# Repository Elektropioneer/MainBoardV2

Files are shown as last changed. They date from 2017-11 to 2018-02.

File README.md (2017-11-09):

# Electropioneer Main Board 
This repo is dedicated to developing the new Main Board for the Electropioneer team
## Software
We are using KiCAD to develop the PCB
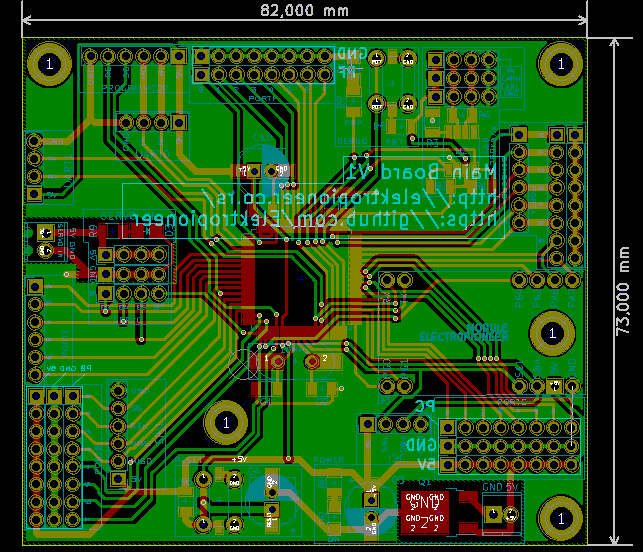
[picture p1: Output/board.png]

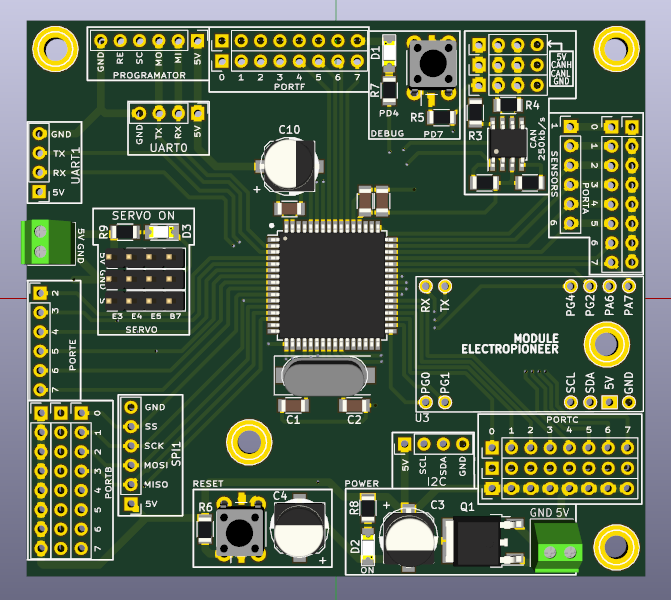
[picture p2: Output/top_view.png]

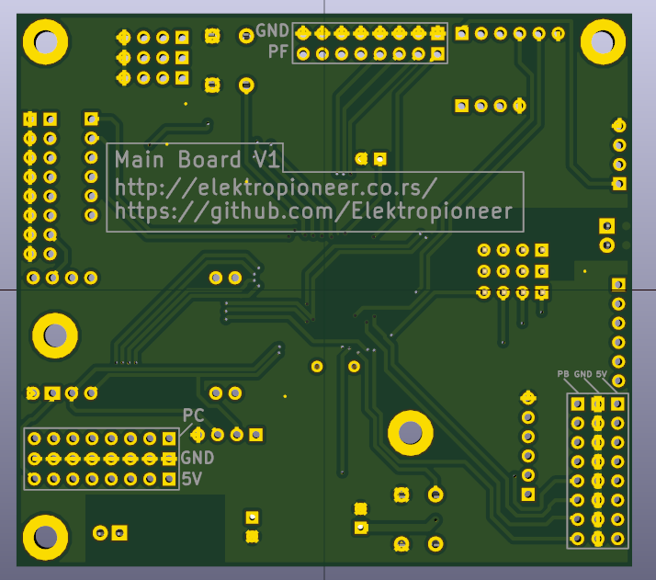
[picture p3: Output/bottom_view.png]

SCHEMATIC PDF

## Protection from reverse current
We are using the simplest way to protect out circuits, a P-Channel MOSFET.
The MOSFET won't turn on when the voltage on the gate is above 0 (exact voltage defined in the datasheet)

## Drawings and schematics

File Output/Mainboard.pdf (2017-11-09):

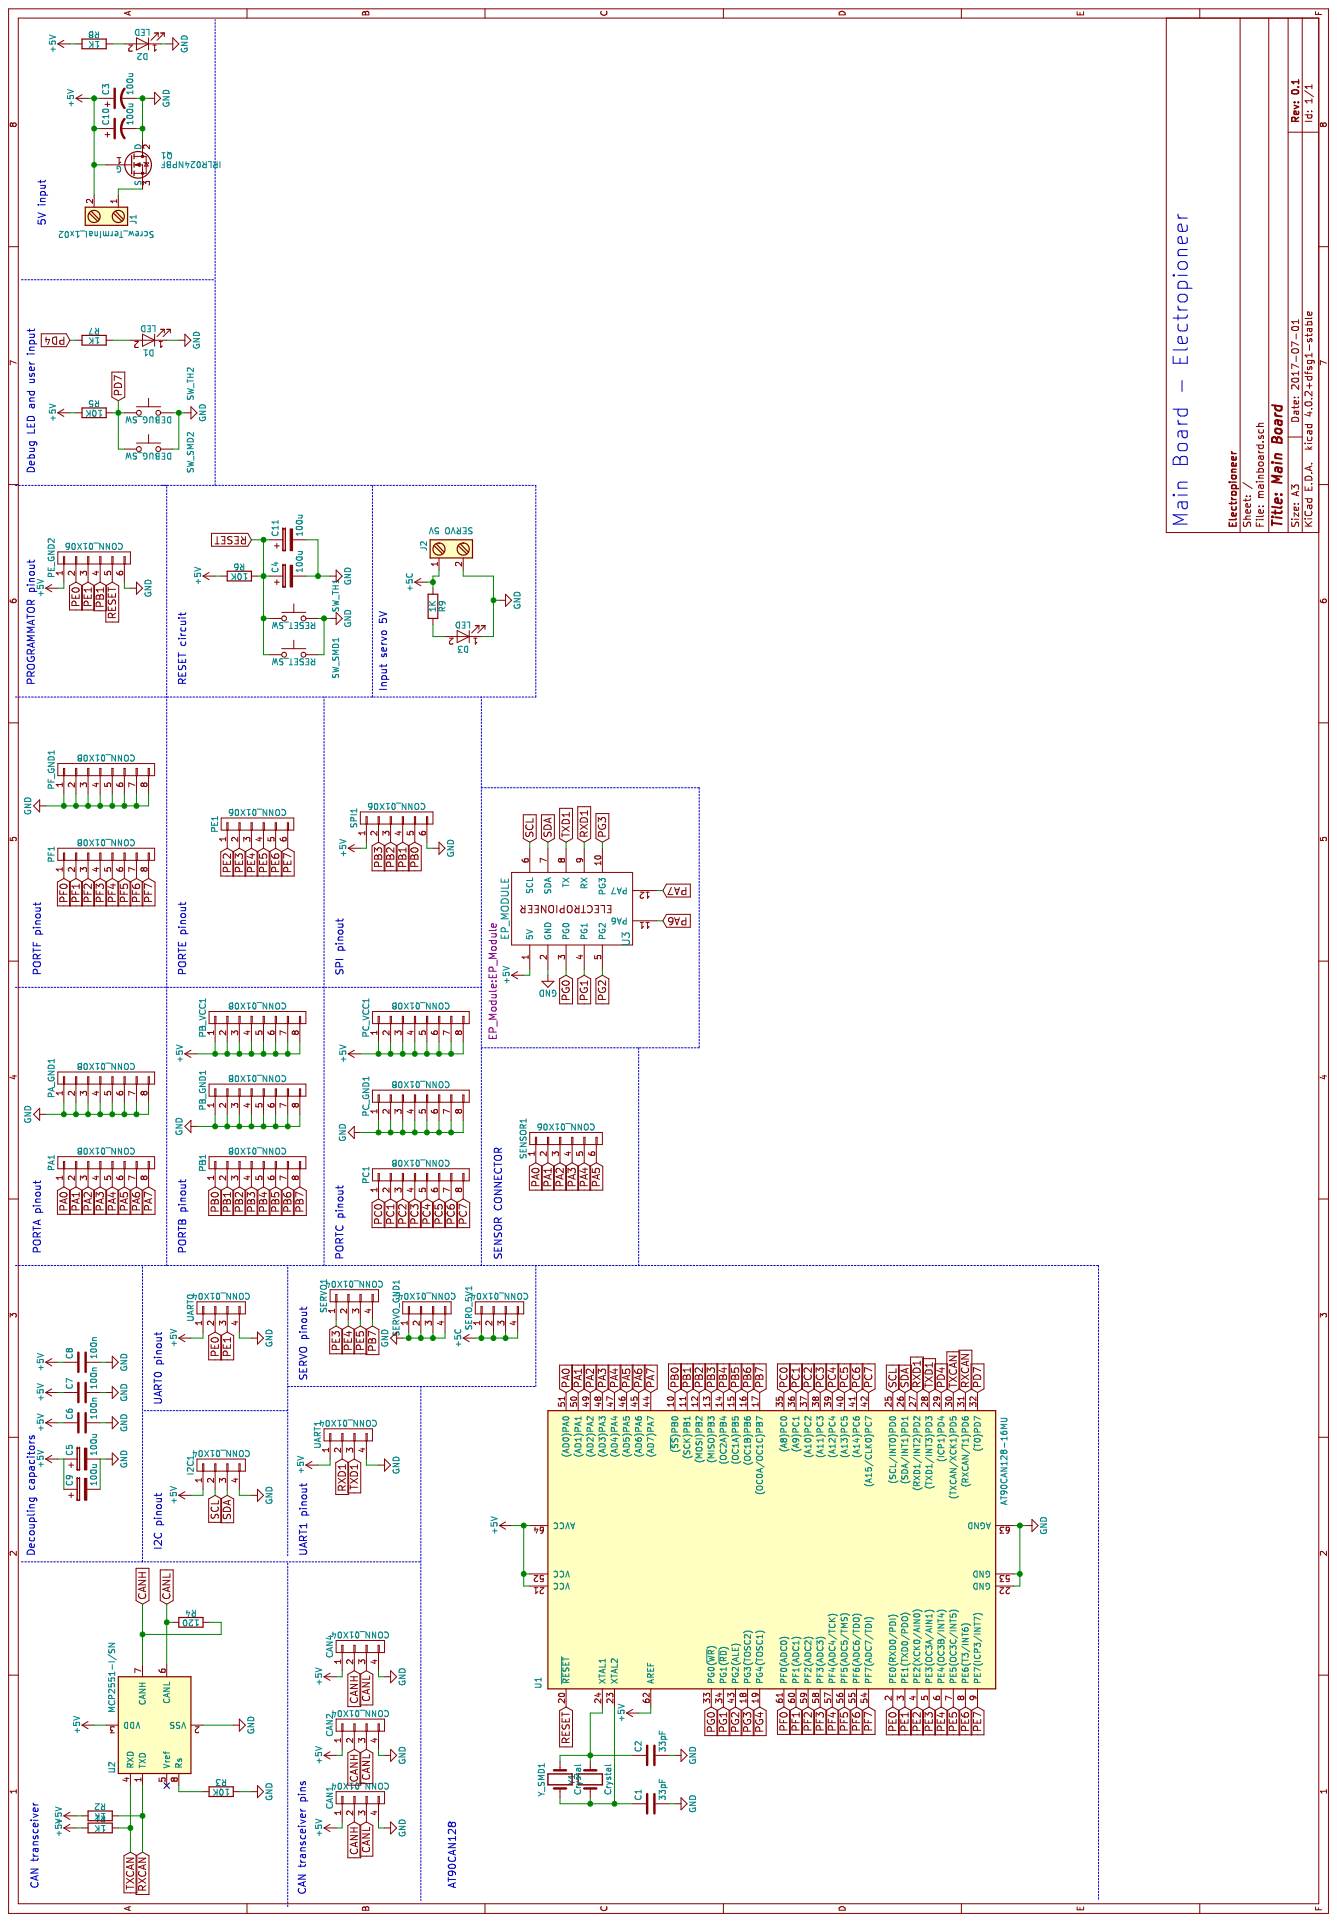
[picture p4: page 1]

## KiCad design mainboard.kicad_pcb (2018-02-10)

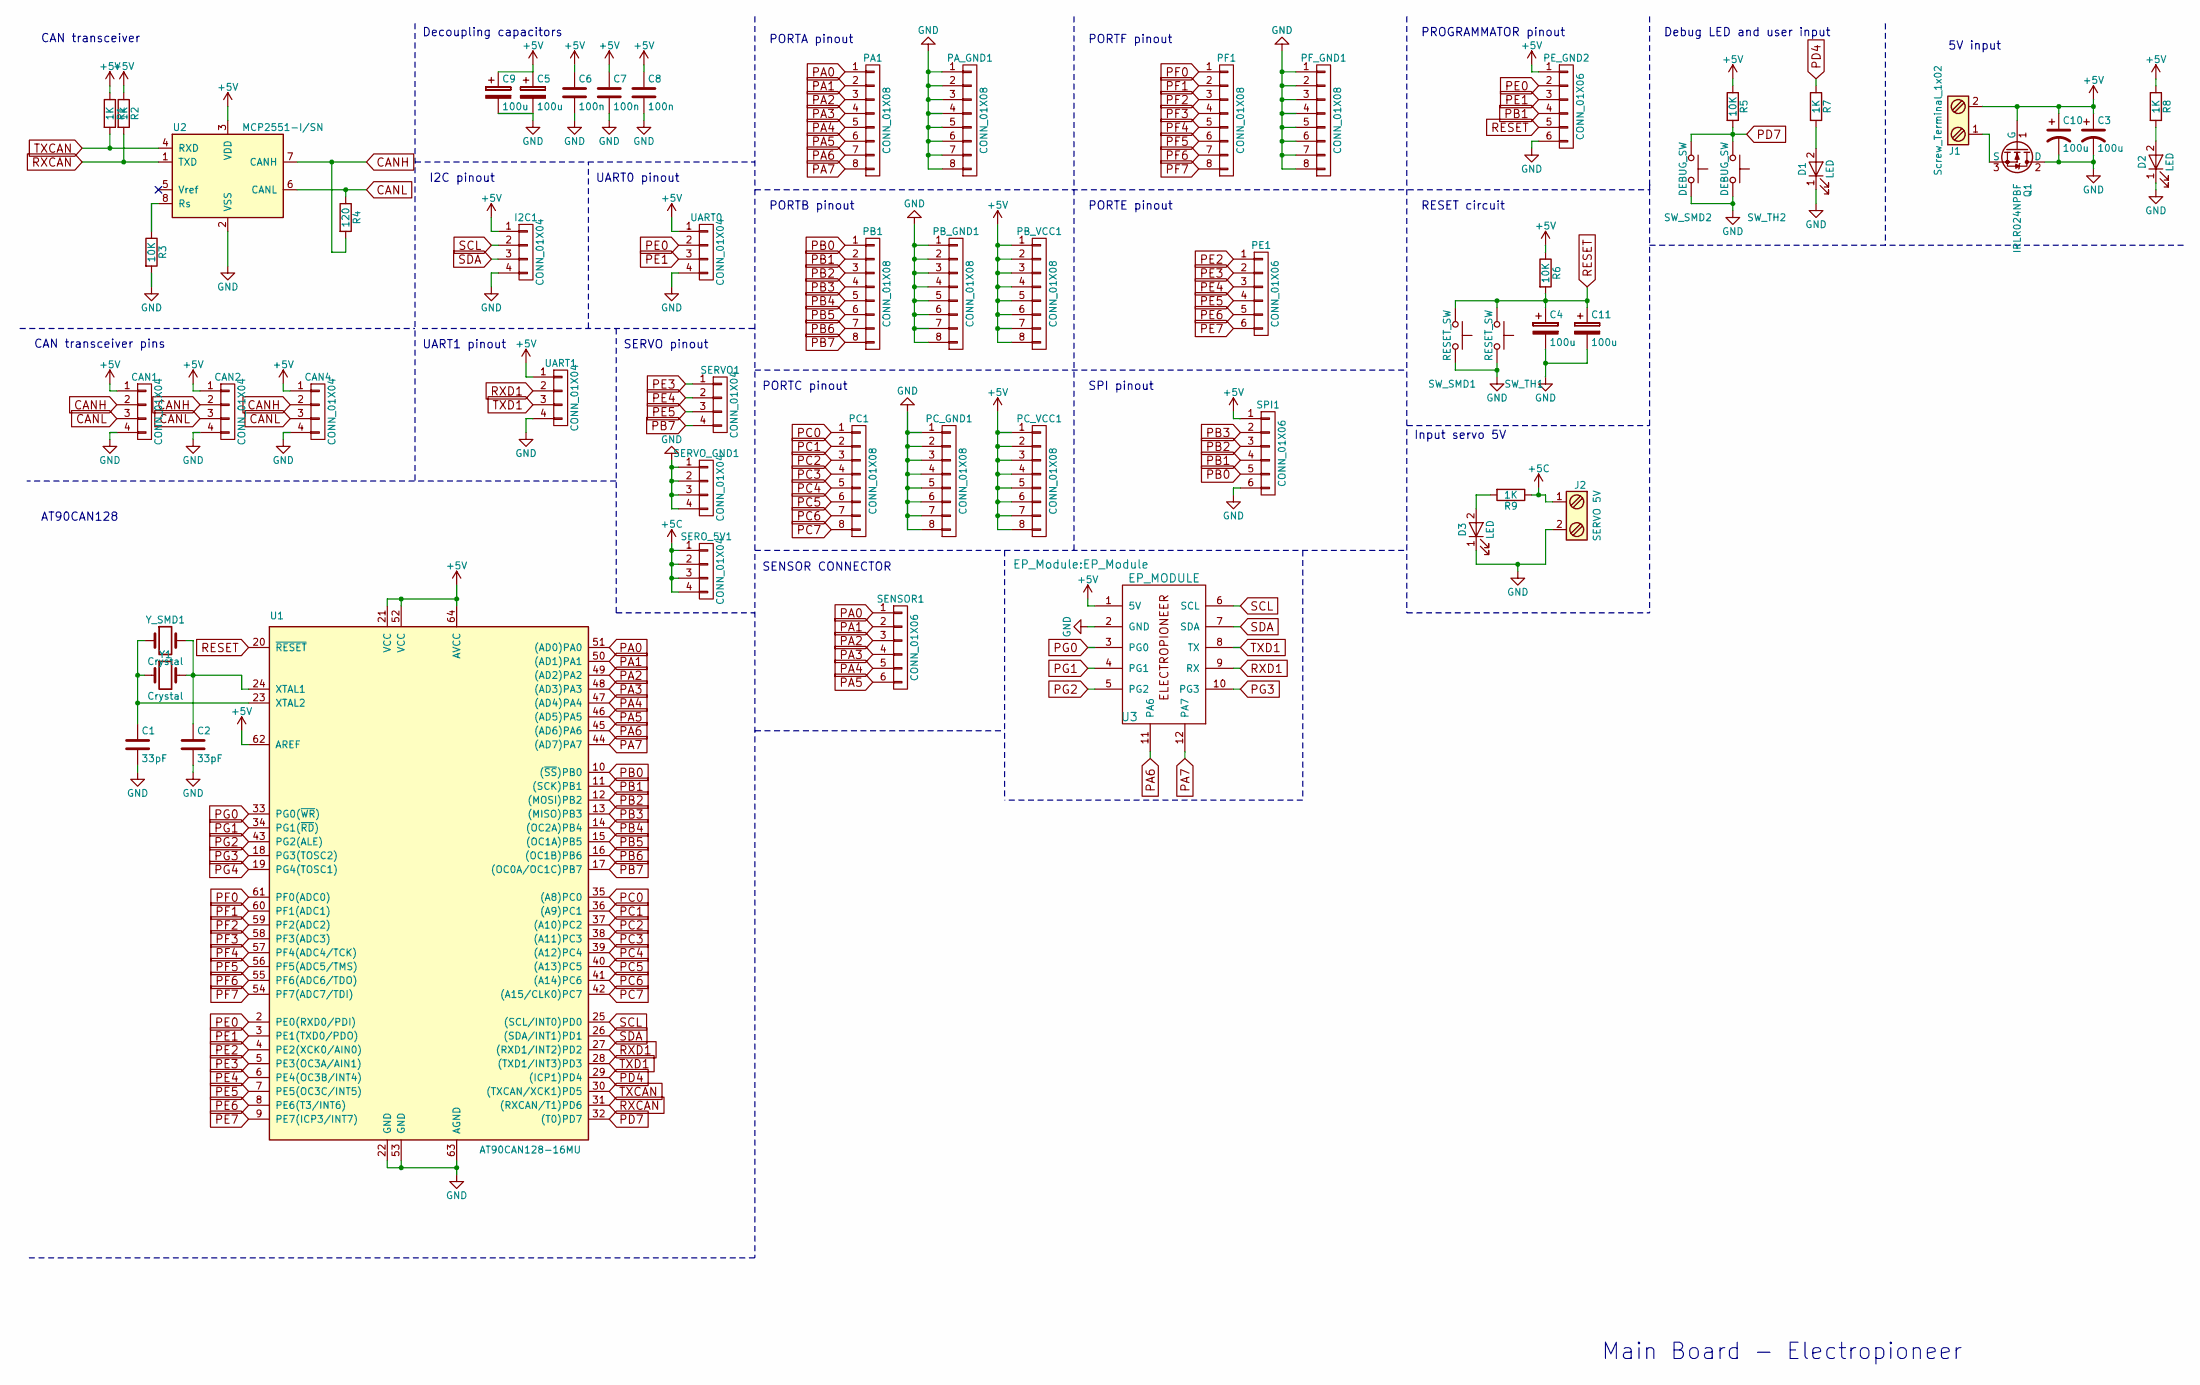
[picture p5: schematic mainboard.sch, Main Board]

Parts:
C1, C2: 33pF; C_0805
C3, C4, C5: 100u; CP_Elec_6.3x4.5
C6, C7, C8: 100n; C_0805
C9, C10, C11: 100u; CP_Radial_D7.5mm_P2.50mm
CAN1, CAN2, CAN4: CONN_01X04; Pin_Header_Straight_1x04_Pitch2.54mm
D1, D2, D3: LED; LED_0805
I2C1: CONN_01X04; Pin_Header_Straight_1x04_Pitch2.54mm
J1: Screw_Terminal_1x02; TerminalBlock_Pheonix_MPT-2.54mm_2pol
J2: SERVO 5V; TerminalBlock_Pheonix_MPT-2.54mm_2pol
PA1: CONN_01X08; Pin_Header_Straight_1x08_Pitch2.54mm
PA_GND1: CONN_01X08; Pin_Header_Straight_1x08_Pitch2.54mm
PB1: CONN_01X08; Pin_Header_Straight_1x08_Pitch2.54mm
PB_GND1: CONN_01X08; Pin_Header_Straight_1x08_Pitch2.54mm
PB_VCC1: CONN_01X08; Pin_Header_Straight_1x08_Pitch2.54mm
PC1: CONN_01X08; Pin_Header_Straight_1x08_Pitch2.54mm
PC_GND1: CONN_01X08; Pin_Header_Straight_1x08_Pitch2.54mm
PC_VCC1: CONN_01X08; Pin_Header_Straight_1x08_Pitch2.54mm
PE1: CONN_01X06; Pin_Header_Straight_1x06_Pitch2.54mm
PE_GND2: CONN_01X06; Pin_Header_Straight_1x06_Pitch2.54mm
PF1: CONN_01X08; Pin_Header_Straight_1x08_Pitch2.54mm
PF_GND1: CONN_01X08; Pin_Header_Straight_1x08_Pitch2.54mm
Q1: IRLR024NPBF; TO-252-2
R1, R2, R7, R8, R9: 1K; R_0805
R3, R5: 10K; R_0805
R4: 120; R_0805
R6: 10K; R_1206
SENSOR1: CONN_01X06; Pin_Header_Straight_1x06_Pitch2.54mm
SERO_5V1: CONN_01X04; Pin_Header_Straight_1x04_Pitch2.54mm
SERVO1: CONN_01X04; Pin_Header_Straight_1x04_Pitch2.54mm
SERVO_GND1: CONN_01X04; Pin_Header_Straight_1x04_Pitch2.54mm
SPI1: CONN_01X06; Pin_Header_Straight_1x06_Pitch2.54mm
SW_SMD1: RESET_SW; SW_DIP_x1_W7.62mm_Slide_Copal_CHS-B
SW_SMD2: DEBUG_SW; SW_DIP_x1_W7.62mm_Slide_Copal_CHS-B
SW_TH1: RESET_SW; SW_PUSH_6mm
SW_TH2: DEBUG_SW; SW_PUSH_6mm
U1: AT90CAN128-16MU; TQFP-64_14x14mm_Pitch0.8mm
U2: MCP2551-I/SN; SOIC-8_3.9x4.9mm_Pitch1.27mm
U3: EP_MODULE; EP_Module
UART0, UART1: CONN_01X04; Pin_Header_Straight_1x04_Pitch2.54mm
Y1: Crystal; Crystal_HC18-U_Vertical
Y_SMD1: Crystal; Crystal_SMD_HC49-SD

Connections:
+5C: J2.1, R9.1, SERO_5V1.1, SERO_5V1.2, SERO_5V1.3, SERO_5V1.4
+5V: C3.1, C5.1, C6.1, C7.1, C8.1, C9.1, C10.1, CAN1.1, CAN2.1, CAN4.1, I2C1.1, J1.2, PB_VCC1.1, PB_VCC1.2, PB_VCC1.3, PB_VCC1.4, PB_VCC1.5, PB_VCC1.6, PB_VCC1.7, PB_VCC1.8, PC_VCC1.1, PC_VCC1.2, PC_VCC1.3, PC_VCC1.4, PC_VCC1.5, PC_VCC1.6, PC_VCC1.7, PC_VCC1.8, PE_GND2.1, Q1.1 (G), R1.1, R2.1, R5.1, R6.1, R8.1, SPI1.1, U1.21 (VCC), U1.52 (VCC), U1.62 (AREF), U1.64 (AVCC), U2.3 (VDD), U3.1 (5V), UART0.1, UART1.1
CANH: CAN1.2, CAN2.2, CAN4.2, R4.2, U2.7 (CANH)
CANL: CAN1.3, CAN2.3, CAN4.3, R4.1, U2.6 (CANL)
GND: C1.2, C2.2, C3.2, C4.2, C5.2, C6.2, C7.2, C8.2, C9.2, C10.2, C11.2, CAN1.4, CAN2.4, CAN4.4, D1.1 (K), D2.1 (K), D3.1 (K), I2C1.4, J2.2, PA_GND1.1, PA_GND1.2, PA_GND1.3, PA_GND1.4, PA_GND1.5, PA_GND1.6, PA_GND1.7, PA_GND1.8, PB_GND1.1, PB_GND1.2, PB_GND1.3, PB_GND1.4, PB_GND1.5, PB_GND1.6, PB_GND1.7, PB_GND1.8, PC_GND1.1, PC_GND1.2, PC_GND1.3, PC_GND1.4, PC_GND1.5, PC_GND1.6, PC_GND1.7, PC_GND1.8, PE_GND2.6, PF_GND1.1, PF_GND1.2, PF_GND1.3, PF_GND1.4, PF_GND1.5, PF_GND1.6, PF_GND1.7, PF_GND1.8, Q1.2 (D), R3.2, SERVO_GND1.1, SERVO_GND1.2, SERVO_GND1.3, SERVO_GND1.4, SPI1.6, SW_SMD1.2, SW_SMD2.2, SW_TH1.2, SW_TH2.2, U1.22 (GND), U1.53 (GND), U1.63 (AGND), U2.2 (VSS), U3.2 (GND), UART0.4, UART1.4
unnamed: C1.1, U1.23 (XTAL2), Y1.1, Y_SMD1.1
unnamed: C2.1, U1.24 (XTAL1), Y1.2, Y_SMD1.2
unnamed: D1.2 (A), R7.2
unnamed: D2.2 (A), R8.2
unnamed: D3.2 (A), R9.2
unnamed: J1.1, Q1.3 (S)
unnamed: R3.1, U2.8 (Rs)
PA0: PA1.1, SENSOR1.1, U1.51 ((AD0)PA0)
PA1: PA1.2, SENSOR1.2, U1.50 ((AD1)PA1)
PA2: PA1.3, SENSOR1.3, U1.49 ((AD2)PA2)
PA3: PA1.4, SENSOR1.4, U1.48 ((AD3)PA3)
PA4: PA1.5, SENSOR1.5, U1.47 ((AD4)PA4)
PA5: PA1.6, SENSOR1.6, U1.46 ((AD5)PA5)
PA6: PA1.7, U1.45 ((AD6)PA6), U3.11 (PA6)
PA7: PA1.8, U1.44 ((AD7)PA7), U3.12 (PA7)
PB0: PB1.1, SPI1.5, U1.10 ((~SS~)PB0)
PB1: PB1.2, PE_GND2.4, SPI1.4, U1.11 ((SCK)PB1)
PB2: PB1.3, SPI1.3, U1.12 ((MOSI)PB2)
PB3: PB1.4, SPI1.2, U1.13 ((MISO)PB3)
PB4: PB1.5, U1.14 ((OC2A)PB4)
PB5: PB1.6, U1.15 ((OC1A)PB5)
PB6: PB1.7, U1.16 ((OC1B)PB6)
PB7: PB1.8, SERVO1.4, U1.17 ((OC0A/OC1C)PB7)
PC0: PC1.1, U1.35 ((A8)PC0)
PC1: PC1.2, U1.36 ((A9)PC1)
PC2: PC1.3, U1.37 ((A10)PC2)
PC3: PC1.4, U1.38 ((A11)PC3)
PC4: PC1.5, U1.39 ((A12)PC4)
PC5: PC1.6, U1.40 ((A13)PC5)
PC6: PC1.7, U1.41 ((A14)PC6)
PC7: PC1.8, U1.42 ((A15/CLK0)PC7)
PD4: R7.1, U1.29 ((ICP1)PD4)
PD7: R5.2, SW_SMD2.1, SW_TH2.1, U1.32 ((T0)PD7)
PE0: PE_GND2.2, U1.2 (PE0(RXD0/PDI)), UART0.2
PE1: PE_GND2.3, U1.3 (PE1(TXD0/PDO)), UART0.3
PE2: PE1.1, U1.4 (PE2(XCK0/AIN0))
PE3: PE1.2, SERVO1.1, U1.5 (PE3(OC3A/AIN1))
PE4: PE1.3, SERVO1.2, U1.6 (PE4(OC3B/INT4))
PE5: PE1.4, SERVO1.3, U1.7 (PE5(OC3C/INT5))
PE6: PE1.5, U1.8 (PE6(T3/INT6))
PE7: PE1.6, U1.9 (PE7(ICP3/INT7))
PF0: PF1.1, U1.61 (PF0(ADC0))
PF1: PF1.2, U1.60 (PF1(ADC1))
PF2: PF1.3, U1.59 (PF2(ADC2))
PF3: PF1.4, U1.58 (PF3(ADC3))
PF4: PF1.5, U1.57 (PF4(ADC4/TCK))
PF5: PF1.6, U1.56 (PF5(ADC5/TMS))
PF6: PF1.7, U1.55 (PF6(ADC6/TDO))
PF7: PF1.8, U1.54 (PF7(ADC7/TDI))
PG0: U1.33 (PG0(~WR~)), U3.3 (PG0)
PG1: U1.34 (PG1(~RD~)), U3.4 (PG1)
PG2: U1.43 (PG2(ALE)), U3.5 (PG2)
PG3: U1.18 (PG3(TOSC2)), U3.10 (PG3)
RESET: C4.1, C11.1, PE_GND2.5, R6.2, SW_SMD1.1, SW_TH1.1, U1.20 (~RESET)
RXCAN: R2.2, U1.31 ((RXCAN/T1)PD6), U2.1 (TXD)
RXD1: U1.27 ((RXD1/INT2)PD2), U3.9 (RX), UART1.2
SCL: I2C1.2, U1.25 ((SCL/INT0)PD0), U3.6 (SCL)
SDA: I2C1.3, U1.26 ((SDA/INT1)PD1), U3.7 (SDA)
TXCAN: R1.2, U1.30 ((TXCAN/XCK1)PD5), U2.4 (RXD)
TXD1: U1.28 ((TXD1/INT3)PD3), U3.8 (TX), UART1.3

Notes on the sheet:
CAN transceiver
5V input
Debug LED and user input
CAN transceiver pins
I2C pinout
UART0 pinout
UART1 pinout
SERVO pinout
PORTA pinout
PORTB pinout
PORTC pinout
SPI pinout
PORTE pinout
PORTF pinout
PROGRAMMATOR pinout
RESET circuit
Decoupling capacitors
AT90CAN128
SENSOR CONNECTOR
Input servo 5V
Main Board - Electropioneer

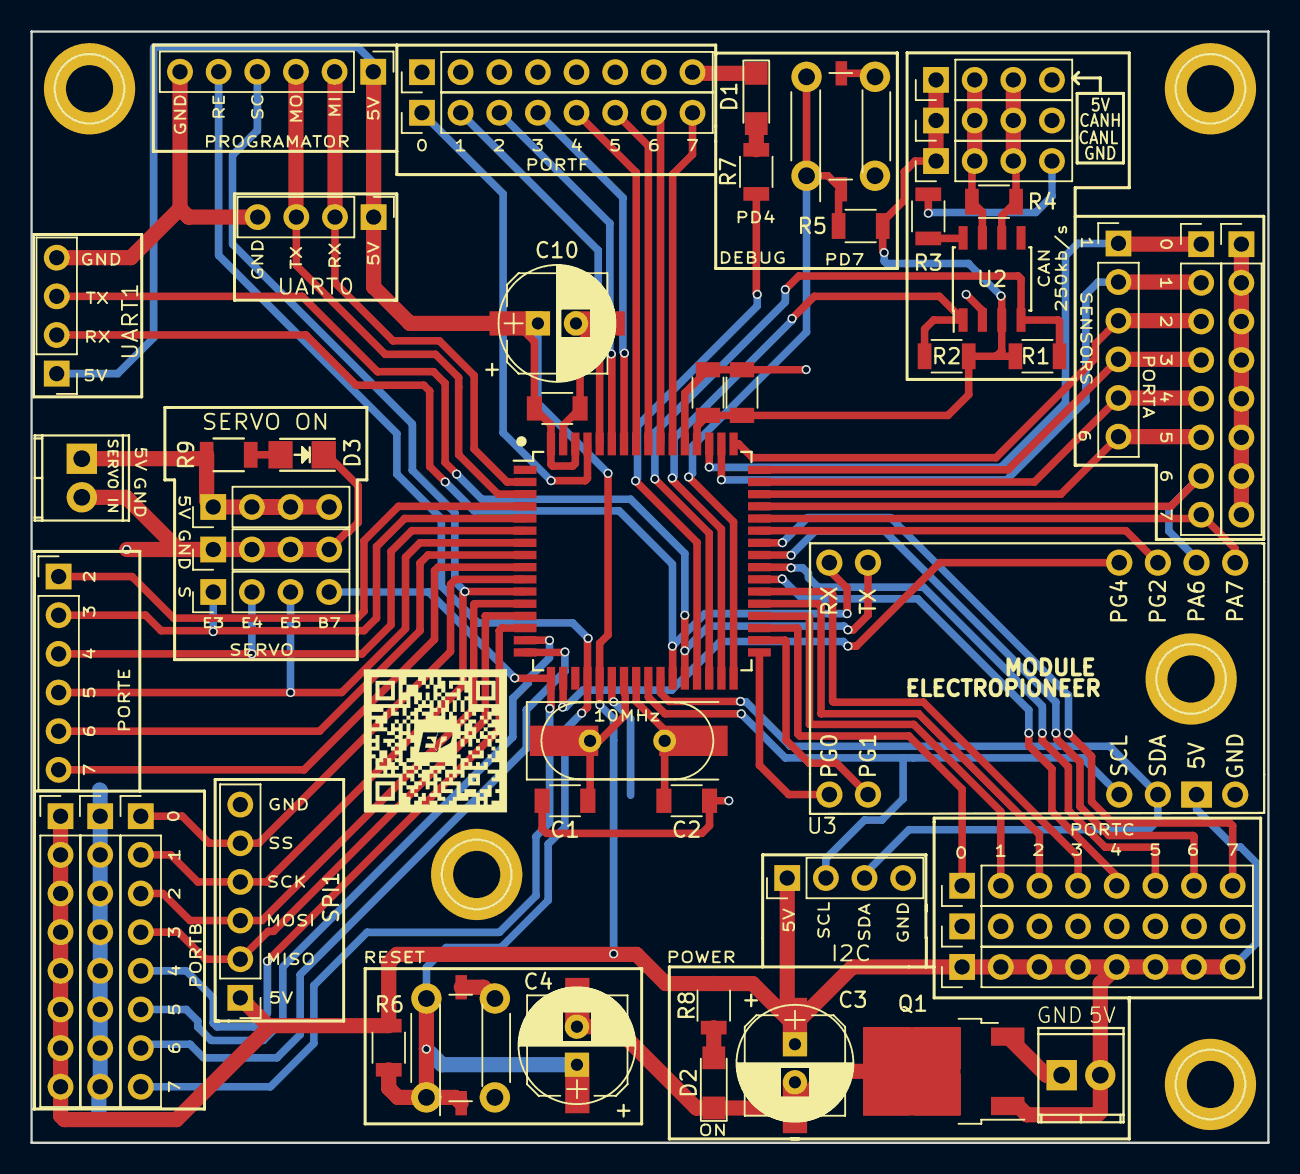
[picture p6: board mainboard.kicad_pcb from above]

Board: 2 copper layers, 81.3 x 73.0 mm, 58 parts (0 on the bottom side), 65 nets.

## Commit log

2017-07-02 Starting to get its form but not there yet
    [mainboard.kicad_pcb, mainboard.sch]
2017-07-03 Added new smd components, still need protection circuit and routing
    [mainboard.kicad_pcb, mainboard.sch]
2017-07-03 Added new smd components, still need protection circuit and routing V2
    [mainboard.kicad_pcb]
2017-07-05 Added protection, made board design and routing
    [mainboard.kicad_pcb, mainboard.sch]
2017-07-05 Removed some trases
    [mainboard.kicad_pcb]
2017-07-05 Removed some trases v2
    [mainboard.kicad_pcb]
2017-07-05 Removed some trases v3
    [mainboard.kicad_pcb]
2017-07-20 Modified mosfet protection to smd
    [mainboard.kicad_pcb, mainboard.sch]
2017-07-20 Updated readme with new file paths and mosfet
2017-07-20 Updated the url for mosfet
2017-09-03 Did some power things
    [mainboard.kicad_pcb, mainboard.sch]
2017-09-03 Added the zone
    [mainboard.kicad_pcb]
2017-10-01 New idea around servo power and new mosfet version for protection
    [mainboard.kicad_pcb, mainboard.sch]
2017-10-01 Added mosfet and servo
    [_saved_mainboard.sch, mainboard.kicad_pcb]
2017-10-01 Added some bottom paste
    [mainboard.kicad_pcb]
2017-10-18 Modified alot of stuff, added module and power for servo
    [_saved_mainboard.sch, mainboard.kicad_pcb, mainboard.sch]
2017-10-18 Modifyed positions around U3
    [mainboard.kicad_pcb]
2017-10-18 Small modif
    [mainboard.kicad_pcb]
2017-10-18 Small modifs, but important
    [mainboard.kicad_pcb, mainboard.sch]
2017-10-22 Changed some footprints from 0603 t 0805
    [mainboard.kicad_pcb, mainboard.sch]
2017-10-28 Final touches
    [mainboard.kicad_pcb]
2017-10-28 Added test DXF
    [mainboard-B.Cu.dxf, mainboard-B.SilkS.dxf, mainboard-F.Cu.dxf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]
2017-11-06 Added output files
    [mainboard-B.Cu.dxf, mainboard-B.SilkS.dxf, mainboard-F.Cu.dxf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]
2017-11-06 Wont export, but it exports .cad
    [mainboard.kicad_pcb]
2017-11-08 Added new wrl file
    [mainboard.kicad_pcb]
2018-02-10 Added EP_Module to glavna
    [mainboard.kicad_pcb, mainboard.sch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]
